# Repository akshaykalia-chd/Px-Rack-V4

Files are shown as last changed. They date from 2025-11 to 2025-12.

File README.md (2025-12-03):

## What is a Px-Rack

Personal Experience Rack, or Px-Rack, is a modular DIY computer rack-style enclosure built for creators who value scalability, customization, and hands-on engineering. Designed to integrate multiple [Mini-ITX](https://en.wikipedia.org/wiki/Mini-ITX) motherboards into a single compact unit, Px-Rack is ideal for homelabs, clustered compute nodes, or multi-OS test environments.

The first use case is [Broadcom VMware Cloud Foundation](https://www.vmware.com/products/cloud-infrastructure/vmware-cloud-foundation). 

### 2-Node Px-Rack Enclosure: ### 
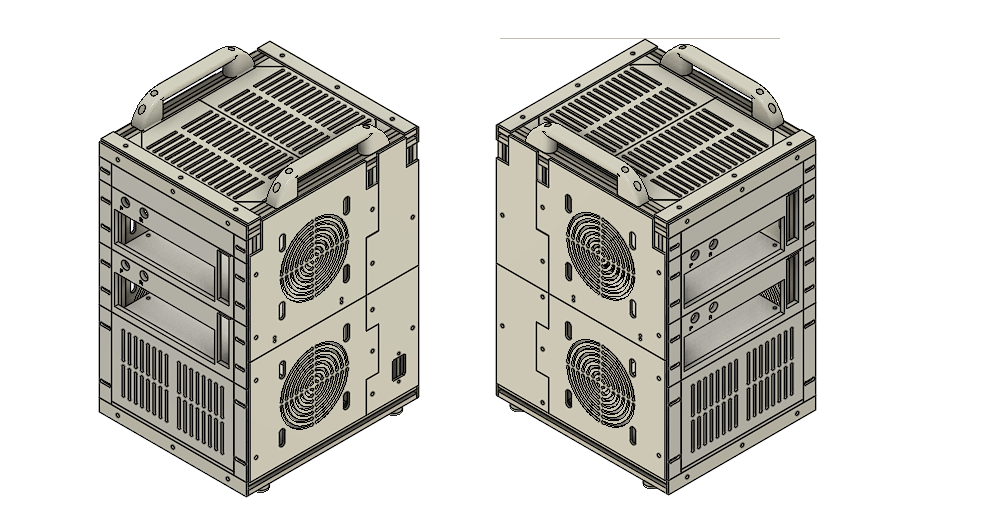
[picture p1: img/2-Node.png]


### 4-Node Px-Rack Enclosure: ### 
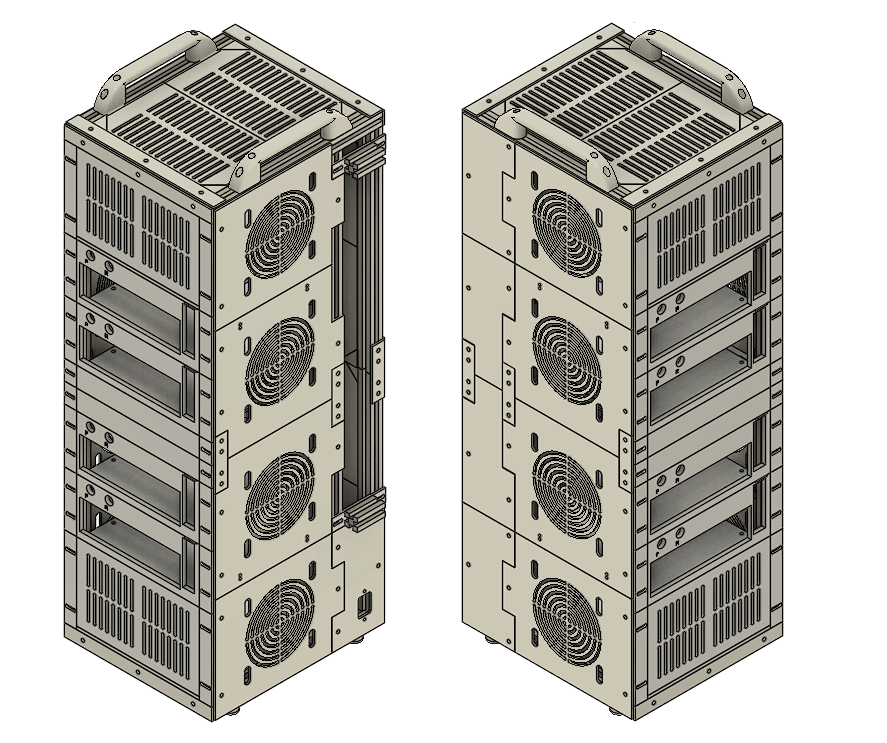
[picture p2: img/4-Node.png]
  

## What sets Px-Rack apart? 

It is Portable, Purpose-Built, and Open-Source

**🔌 Streamlined Power Management**
Unlike traditional racks designed for data centers or server rooms, PX-Rack is purpose-built for commercial hardware. Instead of juggling multiple external power cables, PX-Rack aggregates multiple power supplies into a single external cable using PCT wire connectors.
- No need for extension cords
- No soldering required
- Clean, efficient cable management

**PCT wire connectors:**

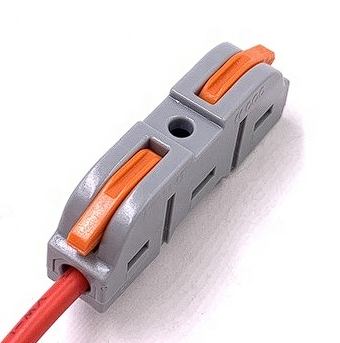
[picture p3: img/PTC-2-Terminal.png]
 
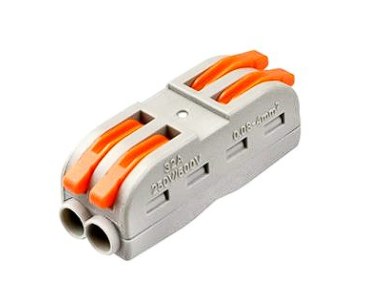
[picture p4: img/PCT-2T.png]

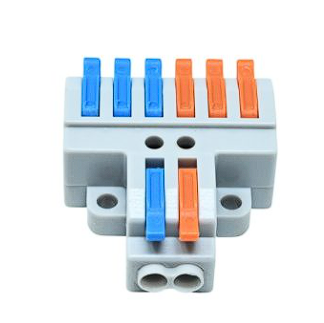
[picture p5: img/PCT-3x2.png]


**📏 Optimized Dimensions**
Width and length — not height — are the critical factors in PX-Rack’s design. This ensures that 10 Gb optical fiber and power cables are neatly tucked inside, reducing clutter and improving accessibility.

**🛠 Maker-Friendly Construction**
Most of PX-Rack’s structural components are 3D-printable, making it accessible and affordable for solo builders and makers.
- STL files available via GitHub
- No proprietary parts
- Community-driven, open-source flexibility

**🌬 Airflow & Multi-Node Freedom**
Whether you’re optimizing airflow, managing cables, or experimenting with multi-node setups, PX-Rack gives you the freedom to build infrastructure your way. It’s a platform designed for experimentation, customization, and scalability.

## Repository stroucture 
```
Px-Rack/
├──2-Node/
│   ├── Data for 2-Node Unit
├──3-Node/   
│   ├── Data for 3-Node Unit
├──4-Node/
│   ├── Data for 4-Node Unit
│
├── STL/
│   ├── ABS/
│   │   ├── PART_001_ABS.stl
│   │   ├── PART_002_ABS.stl
│   │
│   ├── PLA_PETG/
│   │   ├── PART_001_PLA.stl
│   │   ├── PART_002_PLA.stl
└── README.md
    └── Introduction to Px-Rack, build instructions, and licensing.
```
# 📜 Terms and Conditions of Use

By accessing or using the Px-Rack repository, you agree to the following terms:

## 🔧 Personal and Lab Use Only
- This repository is intended solely for **individual, non-commercial use**.
- You may use the provided STL files and documentation to build Px-Rack units for:
  - Personal projects
  - Homelabs
  - Educational setups
  - Non-profit experimentation

## 🚫 Commercial Restrictions
- **Commercial use** of any files, designs, or derivatives is **strictly prohibited** without **explicit written permission** from the repository owner.
- This includes, but is not limited to:
  - Selling printed parts or assembled units
  - Using Px-Rack designs in paid services or commercial installations
  - Distributing modified versions for profit

## 📝 Requesting Permission
- To request commercial usage rights, please contact the repository owner via GitHub or the contact method listed in the main `README.md`.

## 📁 Licensing
- All files are provided "as is" without warranty. Users are responsible for safe printing, assembly, and deployment.
- Redistribution of files must retain original attribution and must not misrepresent the origin or intent of the project.

## 📬 Contact details
- **Name:** Akshay Kalia
- **Email:** akshay@vmzoneblog.com
- **Location:** Bengaluru, Karnataka, India
- **Website:** https://vmzoneblog.com

## FAQs ##

### Why is PDF or STL not loading on Git UI? ###

This behavior is observed when you are connecting to the public GitHub server from a corporate network. Try disabling the VPN and then access the repository.

### What is STL? ###
In 3D printing, STL files are the most common file format used to describe 3D models. STL stands for STereoLithography (or sometimes Standard Triangle Language) and encodes the surface geometry of an object using triangular facets that slicing software can interpret. A slicing software is the tool that converts a 3D model (like an STL file) into layer-by-layer instructions (G-code) that a printer can understand and execute. 

### What is ABS? ###
ABS stands for Acrylonitrile Butadiene Styrene. It is a thermoplastic polymer widely used in 3D printing, especially with FDM (Fused Deposition Modeling) printers. Known for being strong, durable, and impact-resistant, ABS is the same material used in LEGO bricks, car dashboards, and protective housings.

The glass transition temperature of ABS is between 100 and 120 °C. Hence, it is best suited for components operating close to heat-generating parts in the PX-Rack.

### What is PETG? ### 

PETG stands for Polyethylene Terephthalate Glycol-modified. It is a thermoplastic derived from PET (the same plastic used in water bottles), with glycol added to improve durability and reduce brittleness. PETG combines the ease of printing of PLA with the strength and heat resistance of ABS, making it a versatile middle-ground filament.

The glass transition temperature of PETG is between 80 and 100 °C. While it can be used for external parts, it is not suitable for components operating in the vicinity of heat-generating elements in the PX-Rack.

### What is PLA? ###
PLA stands for Polylactic Acid. It is a biodegradable thermoplastic made from renewable resources such as corn starch or sugarcane. PLA is the most widely used filament in desktop 3D printing because it is easy to print, affordable, and environmentally friendly compared to petroleum-based plastics like ABS.

However, the glass transition temperature of PLA lies between 60 and 80 °C. As a result, a large number of PX-Rack components cannot be manufactured using PLA.

PLA should only be used for printing PX-Rack parts as a last resort when printing in PETG is not possible.

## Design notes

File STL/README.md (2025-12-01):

This folder contains all STL files needed to 3D print the various parts of the PX-Rack.

## File Naming Convention

The file names is the folder follow te following pattern 

1. **3d‑YYYY‑MM‑XXX‑XXXXX‑nnnA:** All part numbers with this format must be 3D printed.
   1. *YYYY:* The year in which the part design was last modified. 
   2. *MM:* The month in which the part design was last modified. 
   3. *XXX‑XXXX:* Specifies the material information the part should be printed in. 
   4. *nnnA:* A number followed by a letter. All parts that are joined together to form one unit will share the same numerical portion, followed by an incremental alphabet character.
2. **AAAAAAA‑nnnmm:** All parts with this format must be purchased and cut to length
   1. AAAAAAA: Defines the type of part. 
   2. nnnmm: Length of the part in millimeters. 
3. **AAAAAA‑AAAAA:** All parts with this format must be purchased.

## FAQs ##

### What is STL? ###

In 3D printing, STL files are the most common file format used to describe 3D models. STL stands for STereoLithography (or sometimes Standard Triangle Language) and encodes the surface geometry of an object using triangular facets that slicing software can interpret. A slicing software is the tool that converts a 3D model (like an STL file) into layer-by-layer instructions (G-code) that a printer can understand and execute. 

### What is ABS? ###

ABS stands for Acrylonitrile Butadiene Styrene. It is a thermoplastic polymer widely used in 3D printing, especially with FDM (Fused Deposition Modeling) printers. Known for being strong, durable, and impact-resistant, ABS is the same material used in LEGO bricks, car dashboards, and protective housings.

The glass transition temperature of ABS is between 100 and 120 °C. Hence, it is best suited for components operating close to heat-generating parts in the PX-Rack.

### What is PETG? ### 

PETG stands for Polyethylene Terephthalate Glycol-modified. It is a thermoplastic derived from PET (the same plastic used in water bottles), with glycol added to improve durability and reduce brittleness. PETG combines the ease of printing of PLA with the strength and heat resistance of ABS, making it a versatile middle-ground filament.

The glass transition temperature of PETG is between 80 and 100 °C. While it can be used for external parts, it is not suitable for components operating in the vicinity of heat-generating elements in the PX-Rack.

### What is PLA? ###

PLA stands for Polylactic Acid. It is a biodegradable thermoplastic made from renewable resources such as corn starch or sugarcane. PLA is the most widely used filament in desktop 3D printing because it is easy to print, affordable, and environmentally friendly compared to petroleum-based plastics like ABS.

However, the glass transition temperature of PLA lies between 60 and 80 °C. As a result, a large number of PX-Rack components cannot be manufactured using PLA.

PLA should only be used for printing PX-Rack parts as a last resort when printing in PETG is not possible.

### What quality parameters should be used for 3D prints? ###

You can find these details in the README files located under /STL/ABS and /STL/PLA_PETG.

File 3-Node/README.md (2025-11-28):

## 📑 One Enclosure, Many Paths: The Case Against 3 Node enclosure ##

This section clarifies why PX‑Rack explicitly avoids 3‑Node enclosure configuration, and why the project encourages builders to adopt a 2-Node/4‑Node enclosure as the baseline for scalable, reproducible builds.

**Topology & Symmetry**

1. PX‑Rack emphasizes reproducibility and clarity; a 3‑Node build creates uneven thermal zones and cable routing complexity. 
2. 2-nodes and 4-nodes align with PX‑Rack’s modular philosophy, enabling balanced scaling and straightforward documentation.

**Mechanical & Assembly Considerations**
1. Rack symmetry matters for airflow, load distribution, and cable harnessing. 
2. A 3‑Node setup results in awkward spacing and uneven stress on modular parts. 
3. Documentation clarity suffers because instructions must account for asymmetry, contradicting PX‑Rack’s goal of user‑friendly reproducibility.

**Cost vs. Benefit**
1. The incremental gain from 2 to 3 nodes is marginal compared to the added complexity. 
2. Builders investing in PX‑Rack are better served by scaling directly to 4 nodes, where economies of scale (shared cooling, power distribution, repeatable modules) become meaningful.

**Scalability of the 4‑Node Enclosure**
1. A 4‑Node PX‑Rack enclosure is inherently flexible:
   1. It can host 1 node for entry builds. 
   2. It can expand to 2 nodes. 
   3. It can accommodate 3 nodes if needed, without forcing asymmetry in the enclosure design. 
2. This approach ensures builders are never restricted by their initial enclosure choice. Starting with a 4‑Node frame means growth is always possible without redesign or replacement. 
3. Restricting to a 3-Node enclosure locks builders into a dead‑end path, contradicting PX‑Rack’s philosophy of future‑proof modularity.

## 📌 Conclusion ##

PX‑Rack deliberately avoids 3‑Node configuration because it undermines clarity and reproducibility. Instead, the 2‑Node enclosure is the baseline and 4-Node is the next configuration. 4-Node enclosure supports builds from 1 to 4 nodes, ensuring scalability, symmetry, and future‑proof growth. Builders are encouraged to choose this path to keep every PX‑Rack build accessible, robust, and aligned with the project’s open‑source philosophy.

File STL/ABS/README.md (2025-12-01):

## Folder Contents: ## 

This folder contains 8 STL files as under 

1. 3d-2025-11-ABS-PLUS-001a.stl
2. 3d-2025-11-ABS-PLUS-001b.stl
3. 3d-2025-11-ABS-PLUS-002a.stl
4. 3d-2025-11-ABS-PLUS-002b.stl
5. 3d-2025-11-ABS-PLUS-003a.stl
6. 3d-2025-11-ABS-PLUS-003b.stl
7. 3d-2025-11-ABS-PLUS-004.stl
8. 3d-2025-11-ABS-PLUS-005.stl

The STL must be printed using the following parameters at a minimum. Stronger and higher-quality configurations are acceptable

## 3D Print parameters ##

### Quality ###

1. Material: ABS/ABS+
2. Infill: 50% or above
3. Layer height: 0.28 mm
4. First Layer height: 0.24 mm
5. Precise Wall: True

### Strength ###

1. Top Surface pattern: Rectilinear 
2. Botton Surface pattern:Rectilinear
3. Sparse Infill density: 50% 
4. Sparse Infill pattern: Tri-hexagon
5. Internal solid Infill pattern: Rectilinear

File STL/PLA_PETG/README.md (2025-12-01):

## Folder Contents: ## 

This folder contains 10 STL files as under 

1. 3d-2025-11-PLA-001.stl
2. 3d-2025-11-PLA-002.stl
3. 3d-2025-11-PLA-003.stl
4. 3d-2025-11-PLA-005.stl
5. 3d-2025-11-PLA-006.stl
6. 3d-2025-11-PLA-007.stl
7. 3d-2025-11-PLA-008.stl
8. 3d-2025-11-PLA-009.stl
9. 3d-2025-11-PLA-010.stl
10. 3d-2025-11-PLA-011.stl

The STL must be printed using the following parameters at a minimum. Stronger and higher-quality configurations are acceptable

## 3D Print parameters ##

### Quality ###

1. Material: Ranked recommendation
   1. PETG-Pro
   2. PETG
   3. PLA-Pro
   4. PLA
2. Infill: 50% or above
3. Layer height: 0.28 mm
4. First Layer height: 0.24 mm
5. Precise Wall: True

### Strength ###

1. Top Surface pattern: Rectilinear 
2. Botton Surface pattern:Rectilinear
3. Sparse Infill density: 50% 
4. Sparse Infill pattern: Tri-hexagon
5. Internal solid Infill pattern: Rectilinear

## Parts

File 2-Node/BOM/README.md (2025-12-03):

## Introduction to the 2‑Node PX‑Rack BOM

The file **./BOM/2_NODE_BOM.csv** provides a complete bill of materials required to assemble a 2‑Node PX‑Rack enclosure. This BOM covers all mechanical and structural components necessary for construction.
It is important to note that the listed items do not include any electronic components. The enclosure is designed to give you full flexibility in selecting and integrating your own electronics according to project requirements.
By design, the 2‑Node PX‑Rack supports up to two Mini‑ITX motherboards of your choice. This limitation ensures compactness and structural integrity while still allowing customization of the computing hardware.

The file **./BOM/2_NODE_BOM_electronics.csv** provides a complete bill of materials for the electronic components. Please note that this is a sample list based on the configuration I built. Components that can be customized by the user are marked accordingly.

## Part Naming Convention in the Bill of Materials

The part names is the bill of materials follows the following pattern 
1. **3d‑YYYY‑MM‑XXX‑XXXXX‑nnnA:** All part names with this format must be 3D printed.
   1. *YYYY:* The year in which the part design was last modified. 
   2. *MM:* The month in which the part design was last modified. 
   3. *XXX‑XXXX:* Specifies the material information the part should be printed in. 
   4. *nnnA:* A number followed by a letter. All parts that are joined together to form one unit will share the same numerical portion, followed by an incremental alphabet character.
2. **AAAAAAA‑nnnmm:** All parts names with this format must be purchased and cut to length
   1. AAAAAAA: Defines the type of part. 
   2. nnnmm: Length of the part in millimeters. 
3. **AAAAAA‑AAAAA:** All parts names with this format must be purchased.

### Sample Part Links

**L-Clamp**: https://robu.in/product/easymech-cast-corner-bracket-for-20x20-aluminium-profile-silver-4-pcs/

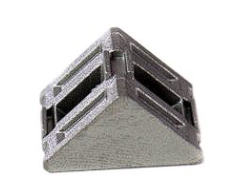
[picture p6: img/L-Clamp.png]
 

**Extrution**:https://robu.in/product/easymech-20x20-t-slot-aluminium-extrusion-profile-1000-mm/

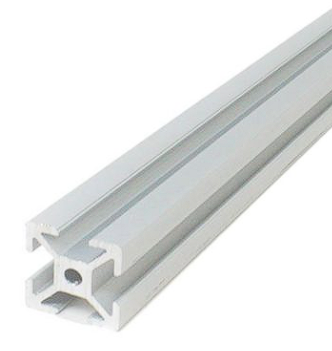
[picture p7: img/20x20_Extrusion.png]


**Mounting T-Nuts**: https://robu.in/product/t-type-m4-nut-for-20x20-aluminium-profile-10-pcs/

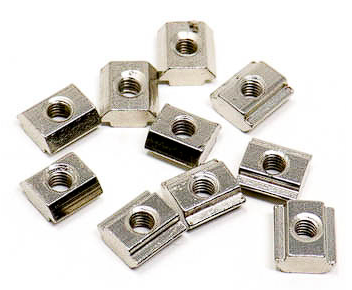
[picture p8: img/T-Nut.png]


**LB12B2-P10F-LANBOO-12mm Economy Push Button Switch**: https://robu.in/product/lb12b2-p10f-lanboo-12mm-economy-push-button-switch-reddc-5-24v1no/ 

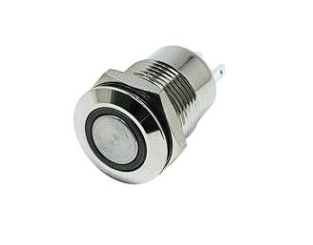
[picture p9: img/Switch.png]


**LB12B2-D1-LANBOO-12mm Economy Push Button Switch Connector**: https://robu.in/product/lb12b2-d1-lanboo-12mm-economy-push-button-switch-connectordc-5-24v/

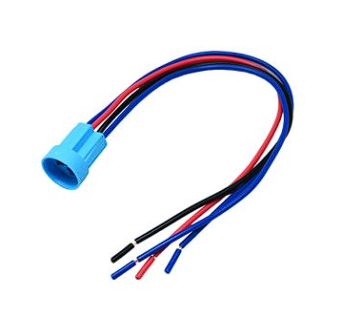
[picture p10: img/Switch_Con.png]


**PCT-223-3 Stationary Type Quick Connection Terminal** : https://robu.in/product/pct-223-3-stationary-type-quick-connection-terminal/

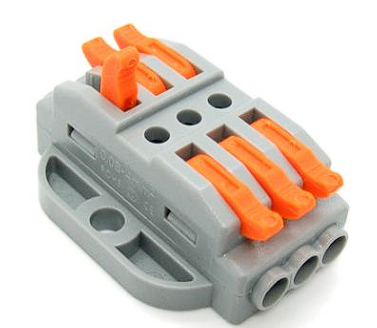
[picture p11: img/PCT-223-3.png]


**LT-633(SPL-63) Stationary, Type Quick Connection, Terminal** : https://robu.in/product/lt-633spl-63-stationary-type-quick-connection-terminal/ 

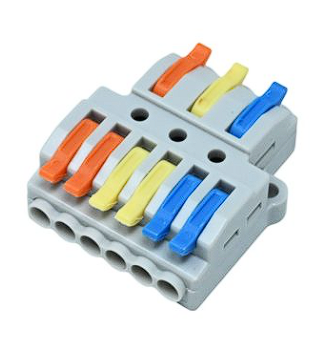
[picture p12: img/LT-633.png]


**LT-933(SPL-93) Stationary Type Quick Connection Terminal**: https://robu.in/product/lt-933spl-93-stationary-type-quick-connection-terminal/ 

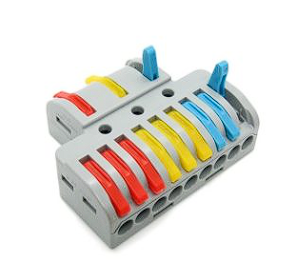
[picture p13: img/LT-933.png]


**IEC C14 Power Inlet Socket with Wires Pre Soldred (Without Fuse)** : https://u1104017.en.made-in-china.com/product/rZBGPcjKlWkD/China-IEC-320-C14-Male-3-Pins-Screw-Mount-Inlet-AC-Power-Plug-Adapter-Connector-Socket-AC-250V-10A-Black-w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



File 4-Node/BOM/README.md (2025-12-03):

## Introduction to the 4‑Node PX‑Rack BOM

The file **./BOM/4_NODE_BOM.csv** provides a complete bill of materials required to assemble a 4‑Node PX‑Rack enclosure. This BOM covers all mechanical and structural components necessary for construction.
It is important to note that the listed items do not include any electronic components. The enclosure is designed to give you full flexibility in selecting and integrating your own electronics according to project requirements.
By design, the 4‑Node PX‑Rack supports up to four Mini‑ITX motherboards of your choice. This limitation ensures compactness and structural integrity while still allowing customization of the computing hardware.

The file **./BOM/4_NODE_BOM_electronics.csv** provides a complete bill of materials for the electronic components. Please note that this is a sample list based on the configuration I built. Components that can be customized by the user are marked accordingly.

## Part Naming Convention in the Bill of Materials

The part names is the bill of materials follows the following pattern 
1. **3d‑YYYY‑MM‑XXX‑XXXXX‑nnnA:** All part names with this format must be 3D printed.
   1. *YYYY:* The year in which the part design was last modified. 
   2. *MM:* The month in which the part design was last modified. 
   3. *XXX‑XXXX:* Specifies the material information the part should be printed in. 
   4. *nnnA:* A number followed by a letter. All parts that are joined together to form one unit will share the same numerical portion, followed by an incremental alphabet character.
2. **AAAAAAA‑nnnmm:** All parts names with this format must be purchased and cut to length
   1. AAAAAAA: Defines the type of part. 
   2. nnnmm: Length of the part in millimeters. 
3. **AAAAAA‑AAAAA:** All parts names with this format must be purchased.

### Sample Part Links

**L-Clamp**: https://robu.in/product/easymech-cast-corner-bracket-for-20x20-aluminium-profile-silver-4-pcs/

 

**Extrution**:https://robu.in/product/easymech-20x20-t-slot-aluminium-extrusion-profile-1000-mm/



**Mounting T-Nuts**: https://robu.in/product/t-type-m4-nut-for-20x20-aluminium-profile-10-pcs/



**LB12B2-P10F-LANBOO-12mm Economy Push Button Switch**: https://robu.in/product/lb12b2-p10f-lanboo-12mm-economy-push-button-switch-reddc-5-24v1no/ 



**LB12B2-D1-LANBOO-12mm Economy Push Button Switch Connector**: https://robu.in/product/lb12b2-d1-lanboo-12mm-economy-push-button-switch-connectordc-5-24v/



**PCT-223-3 Stationary Type Quick Connection Terminal** : https://robu.in/product/pct-223-3-stationary-type-quick-connection-terminal/



**LT-633(SPL-63) Stationary, Type Quick Connection, Terminal** : https://robu.in/product/lt-633spl-63-stationary-type-quick-connection-terminal/ 



**LT-933(SPL-93) Stationary Type Quick Connection Terminal**: https://robu.in/product/lt-933spl-93-stationary-type-quick-connection-terminal/ 



**IEC C14 Power Inlet Socket with Wires Pre Soldred (Without Fuse)** : https://u1104017.en.made-in-china.com/product/rZBGPcjKlWkD/China-IEC-320-C14-Male-3-Pins-Screw-Mount-Inlet-AC-Power-Plug-Adapter-Connector-Socket-AC-250V-10A-Black-w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



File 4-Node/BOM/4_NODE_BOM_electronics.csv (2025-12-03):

Product | Description | Quantity | Customizable
MSI MPG B850I Edge Ti WiFi AM5 Mini-ITX | Mother Board | 4 | Yes, you can use other AM5 MotherBoards as well
AMD RYZEN 9 9950X AM5 DESKTOP PROCESSOR (100-100001277WOF) | CPU | 4 | Yes, Any AM5 CPU should do
128GB (64GBX2) DDR5 6400MHZ UDIMM DESKTOP RAM | RAM | 4 | Yes
512GB SATA III INTERNAL SSD | Boot Disk | 4 | Yes
500GB M.2 NVME INTERNAL SSD | Memory Tier | 4 | Yes
2TB M.2 NVME INTERNAL SSD | vSAN | 4 | Yes
400 Watt ATX Power | Power | 4 | Yes
Noctua NH-L9a-AM5 92mm | CPU Cooler | 4 | Yes
Intel 10G Nic x710-DA2 SFP+ | 10g Nic SPF+ | 4 | Yes, any Supprted 10G 10g Nic with SPF+ or RJ45 Should do
TP-Link TL-SM5310-T | 10GBase-T RJ45 SFP+ Module | SPF+ to RJ 45 | 2 | Yes, Buy based on Switch selection
TP-Link TL-SX3016F | 16 Port 10G SFP+ | 10G Switch | 1 | Yes, any 10G swith with VLAN Support should do
SPF+ cable | SPF+ cable | 8 | Yes, Buy based on Switch selection
LB12B2-P10F-LANBOO-12mm Economy Push Button Switch | Power & Reset switch | 8 | No
LB12B2-D1-LANBOO-12mm Economy Push Button Switch Connector | Power & Reset switch Wires | 8 | No
PCT-223-3 Stationary Type Quick Connection Terminal | PCT wire connectors | 4 | No
LT-633(SPL-63) Stationary, Type Quick Connection, Terminal | PCT wire connectors | 2 | No
LT-933(SPL-93) Stationary Type Quick Connection Terminal | PCT wire connectors | 1 | No
IEC C14 Power Inlet Socket with Wires Pre Soldered (Without Fuse) | AC Power Inlet | 1 | No

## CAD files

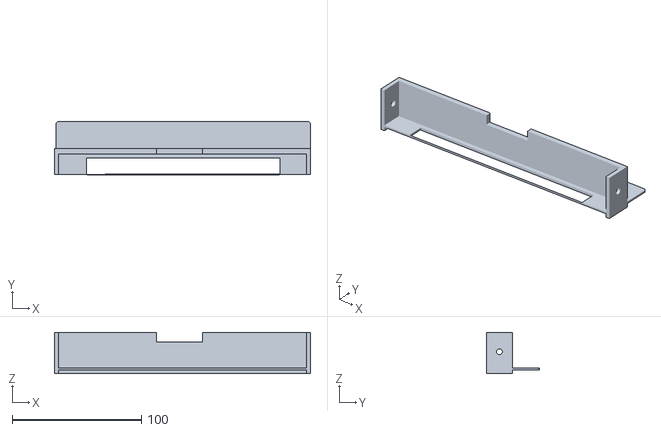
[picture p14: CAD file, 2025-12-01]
STL/ABS/3d-2025-11-ABS-PLUS-001b.stl
198.0 x 41.0 x 32.0

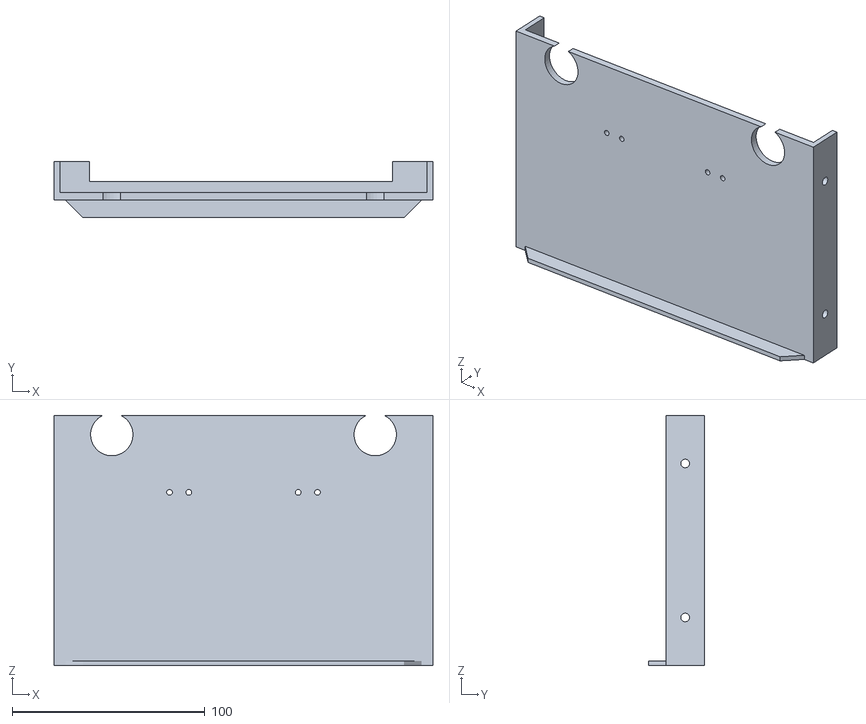
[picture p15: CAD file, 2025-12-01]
STL/ABS/3d-2025-11-ABS-PLUS-003b.stl
196.8 x 29.0 x 130.0

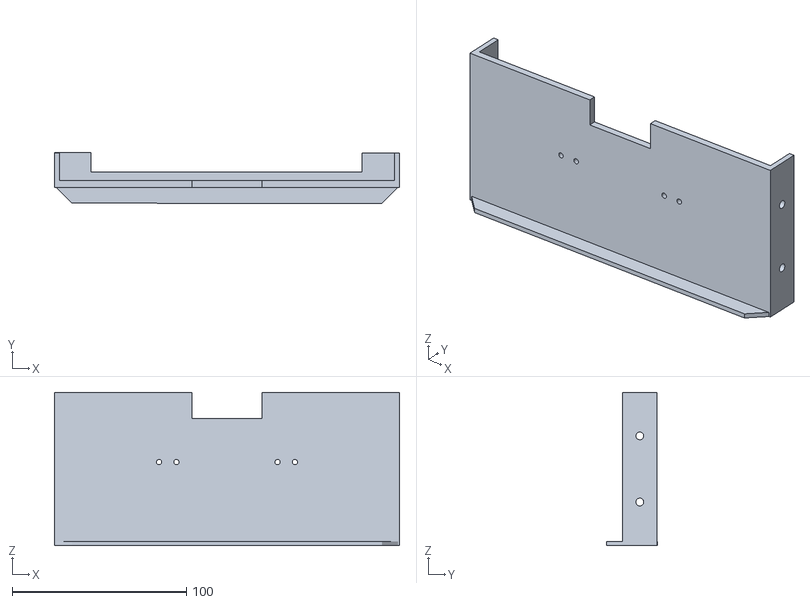
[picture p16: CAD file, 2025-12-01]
STL/ABS/3d-2025-11-ABS-PLUS-002b.stl
198.0 x 29.0 x 88.0

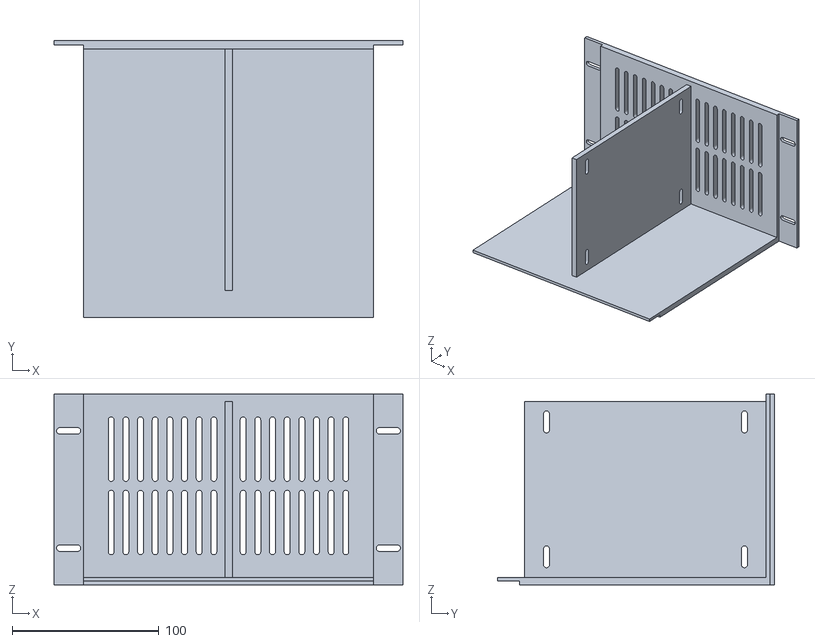
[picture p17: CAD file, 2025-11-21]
STL/ABS/3d-2025-11-ABS-PLUS-003a.stl
238.0 x 189.0 x 130.0

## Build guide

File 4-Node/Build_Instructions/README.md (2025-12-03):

## PX-Rack 4-Node Enclosure Assembly Overview
The directory contains PDF files showing the various steps involved in assembling the PX-Rack 4-node enclosure.

Each step includes a parts list along with the required mounting screws and nuts. Before starting to follow the drawings in this section, make sure you have purchased all the required components and 3D-printed all the necessary parts.

**The build steps do not cover electronics integration.** This is intentional. Before ordering the electronics and attempting integration, I recommend that you fully assemble the PX-Rack enclosure.

However, Electronics integration will take place after **Step-3**, and by the end of **Step-5** all electronics should be in place, except for the ventilation fans. The fans will be installed after **Step-5** and before **Step-7**.

*Electronics integration is slightly nuanced and cannot be explained adequately using drawings. I will include videos for this process in the near future.*



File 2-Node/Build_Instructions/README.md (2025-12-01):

## PX-Rack 2-Node Enclosure Assembly Overview
The directory contains PDF files showing the various steps involved in assembling the PX-Rack 2-node enclosure.

Each step includes a parts list along with the required mounting screws and nuts. Before starting to follow the drawings in this section, make sure you have purchased all the required components and 3D-printed all the necessary parts.

**The build steps do not cover electronics integration.** This is intentional. Before ordering the electronics and attempting integration, I recommend that you fully assemble the PX-Rack enclosure.

However, Electronics integration will take place after **Step-2**, and by the end of **Step-3** all electronics should be in place, except for the ventilation fans. The fans will be installed after **Step-4** and before **Step-5**.

*Electronics integration is slightly nuanced and cannot be explained adequately using drawings. I will include videos for this process in the near future.*



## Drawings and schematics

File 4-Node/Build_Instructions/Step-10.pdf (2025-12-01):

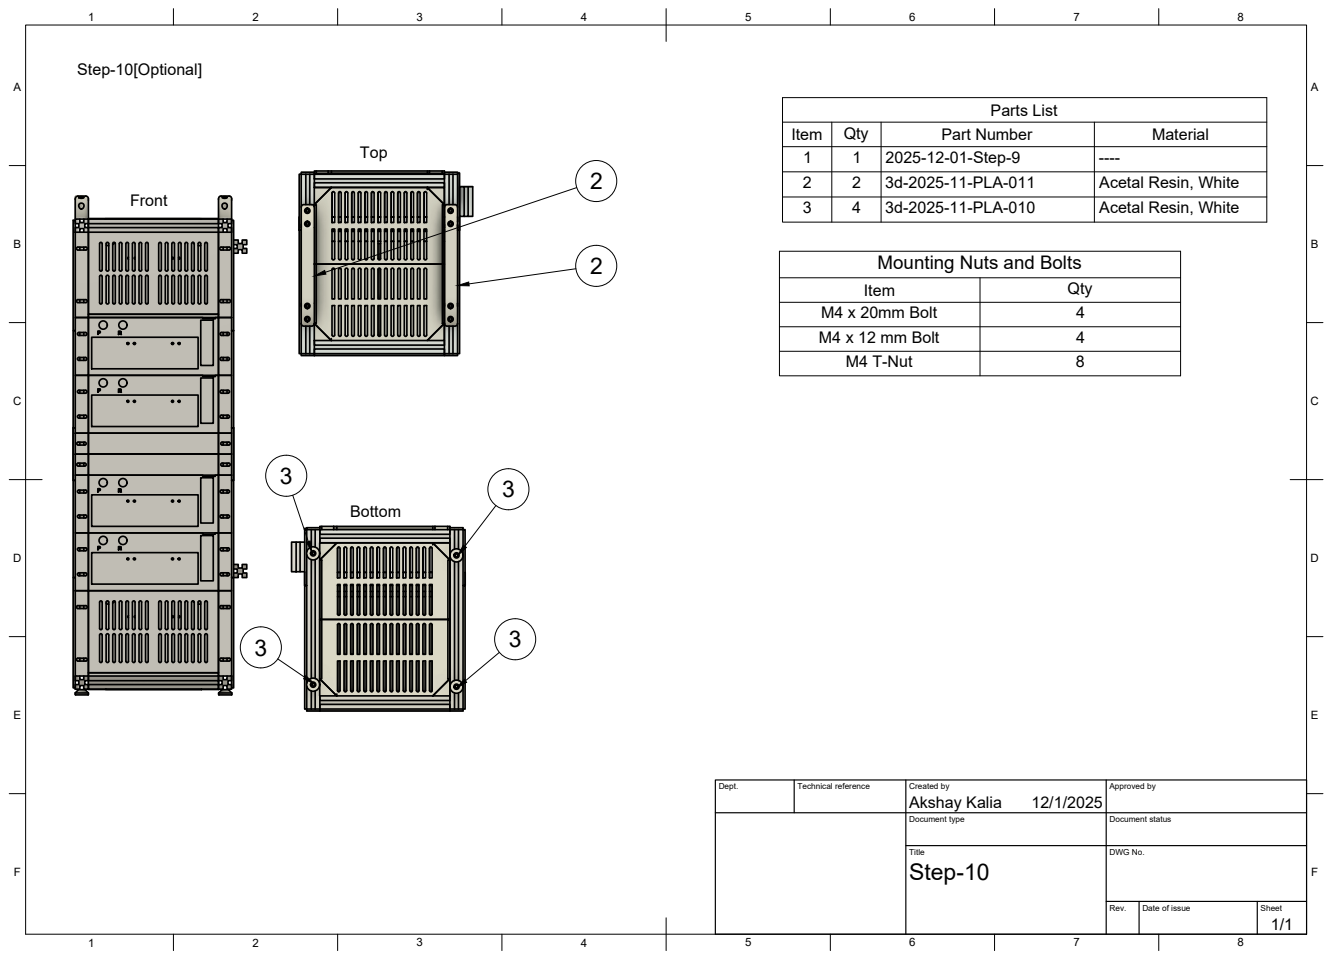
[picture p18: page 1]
Title; DWG No.; Rev.; Date of issue; Sheet; Parts List

Item | Qty | Part Number | Material
1 | 2 1 | 3d-2025-11-PLA-011 2025-12-01-Step-9 | ---- 2 Acetal Resin, White

3 | 4 | 3d-2025-11-PLA-010 | Acetal Resin, White

Mounting Nuts and Bolts

Item | Qty
M4 x 20mm Bolt | 4
M4 x 12 mm Bolt | 4
M4 T-Nut | 8

Dept. | Technical reference | Created by Akshay Kalia 12/1/2025 | Approved by

Document type | Document status

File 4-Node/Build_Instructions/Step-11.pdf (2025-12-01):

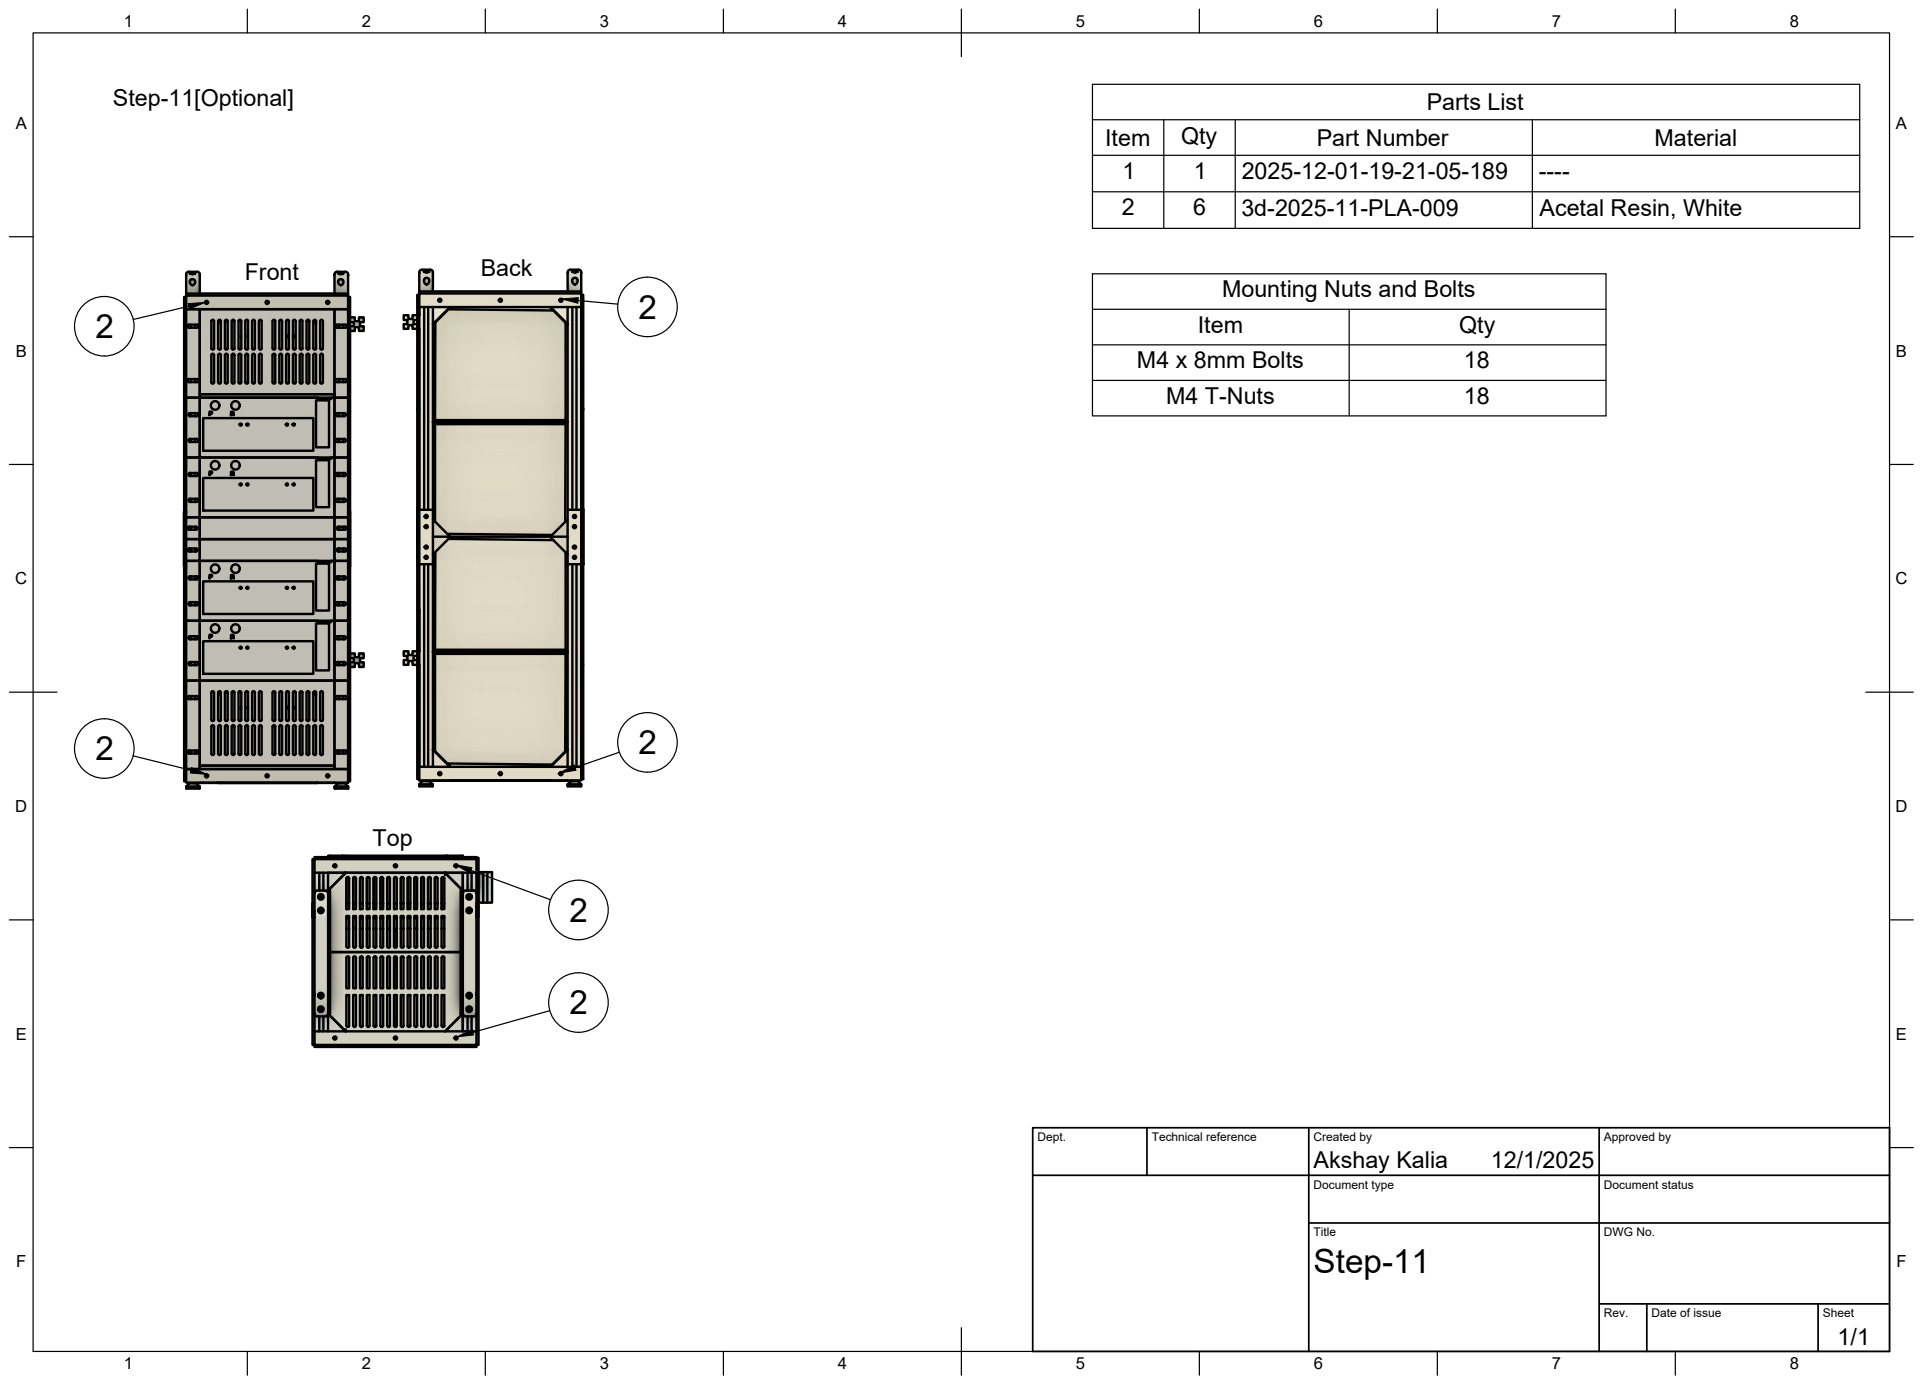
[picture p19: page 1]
Title; DWG No.; Rev.; Date of issue; Sheet; Parts List

Item | Qty | Part Number | Material
1 | 6 1 | 3d-2025-11-PLA-009 2025-12-01-19-21-05-189 | ---- 2 Acetal Resin, White

Mounting Nuts and Bolts

Item | Qty
M4 x 8mm Bolts | 18
M4 T-Nuts | 18

Dept. | Technical reference | Created by Akshay Kalia 12/1/2025 | Approved by

Document type | Document status

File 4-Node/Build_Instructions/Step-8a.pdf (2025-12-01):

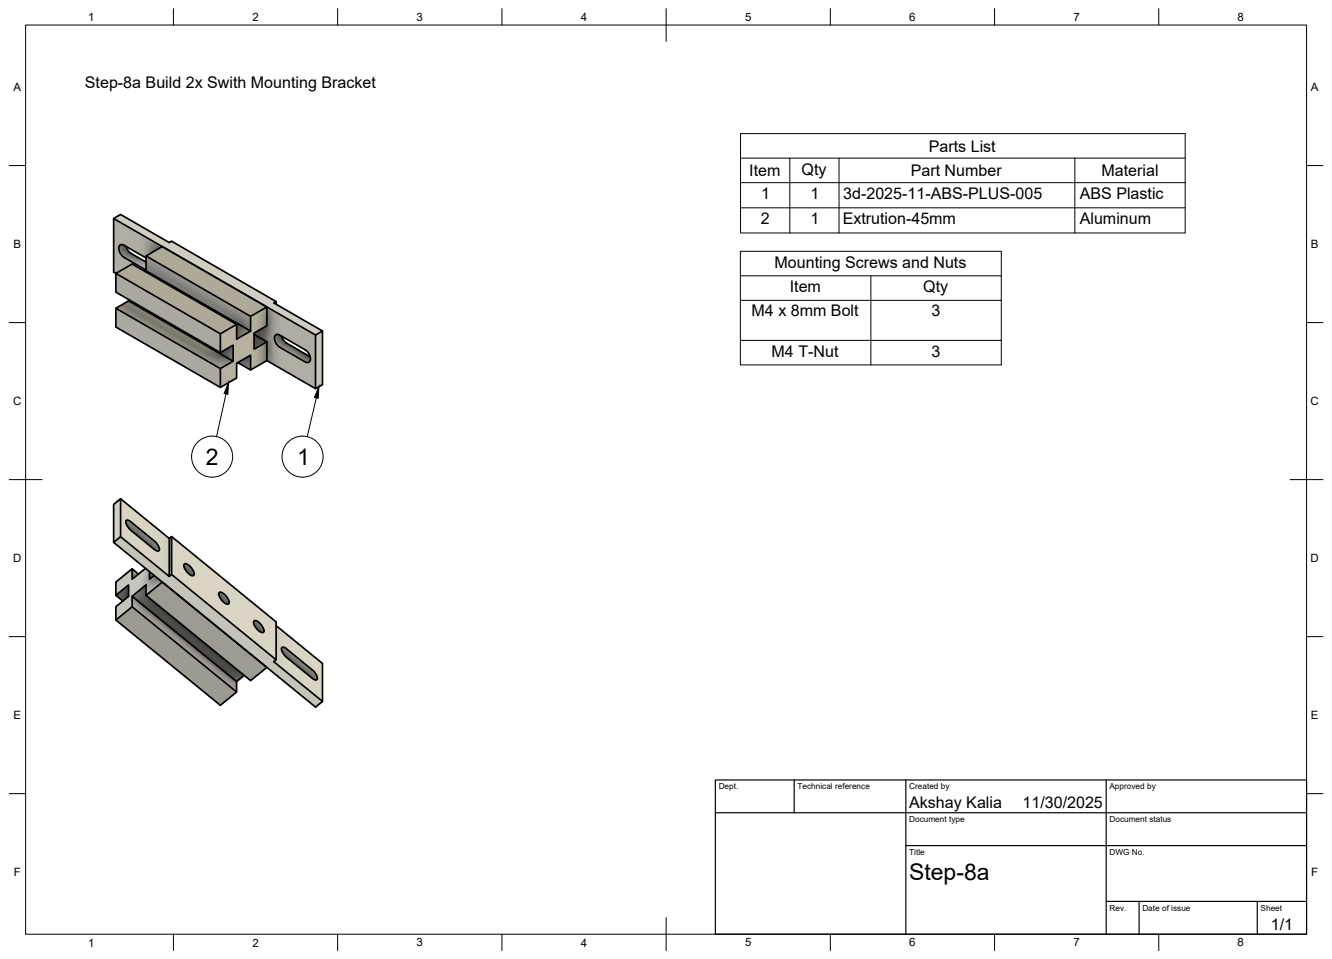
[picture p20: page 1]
Title; DWG No.; Rev.; Date of issue; Sheet; Parts List

Step-8a Build 2x Swith Mounting Bracket

Item | Qty | Part Number | Material
1 | 1 | 3d-2025-11-ABS-PLUS-005 | ABS Plastic
2 | 1 | Extrution-45mm | Aluminum

Mounting Screws and Nuts

Item | Qty
M4 x 8mm Bolt | 3

M4 T-Nut | 3

Dept. | Technical reference | Created by Akshay Kalia 11/30/2025 | Approved by

Document type | Document status

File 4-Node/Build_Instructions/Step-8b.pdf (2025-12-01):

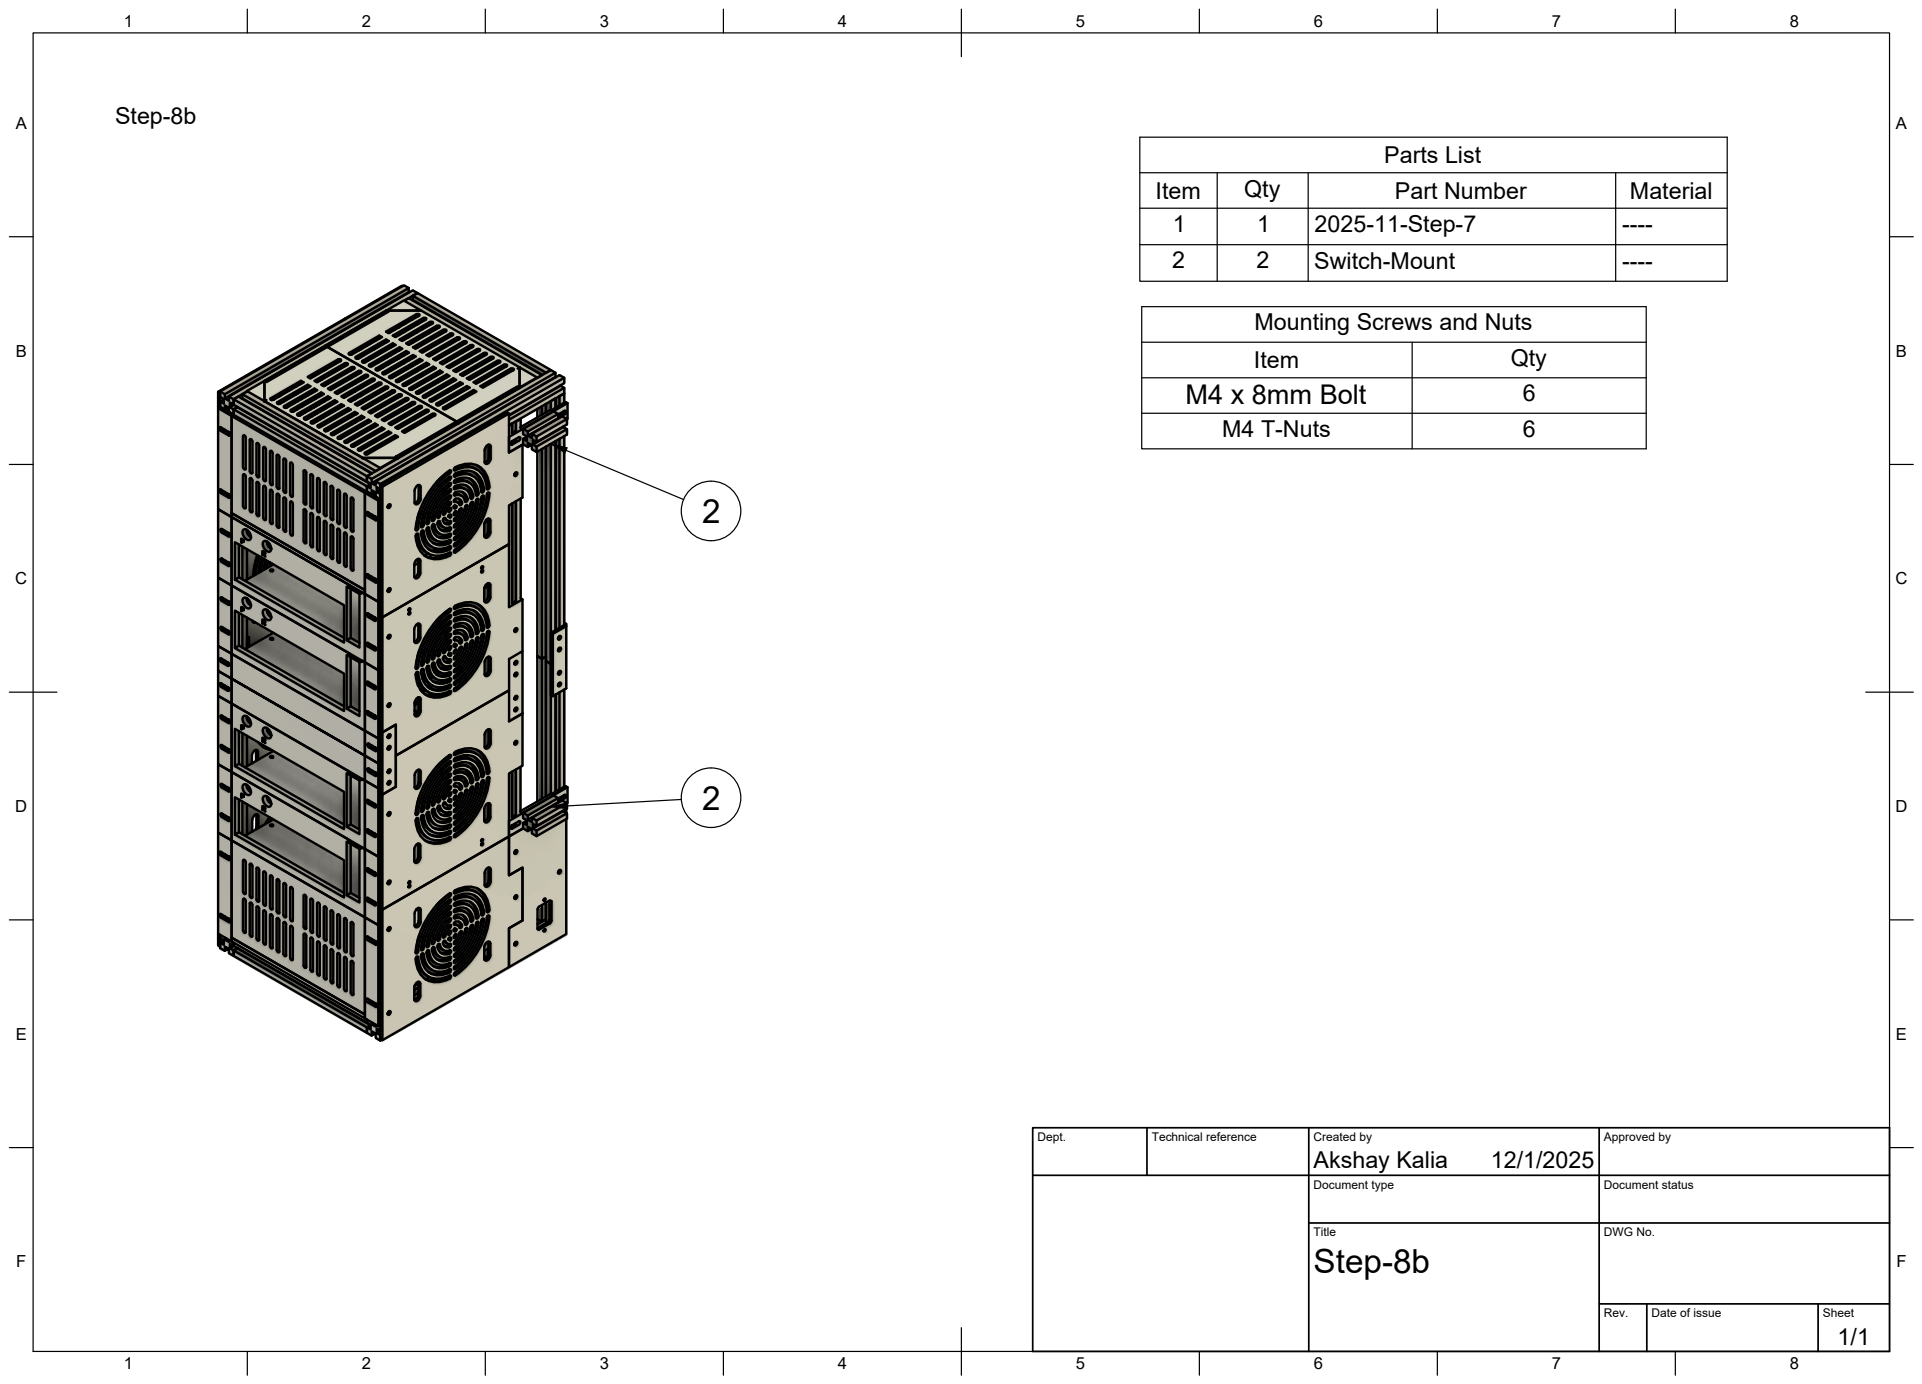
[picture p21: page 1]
Title; DWG No.; Rev.; Date of issue; Sheet; Parts List

Item | Qty | Part Number | Material
1 | 2 1 | Switch-Mount 2025-11-Step-7 | ---- 2 ----

Mounting Screws and Nuts

Item | Qty
M4 x 8mm Bolt | 6
M4 T-Nuts | 6

Dept. | Technical reference | Created by Akshay Kalia 12/1/2025 | Approved by

Document type | Document status

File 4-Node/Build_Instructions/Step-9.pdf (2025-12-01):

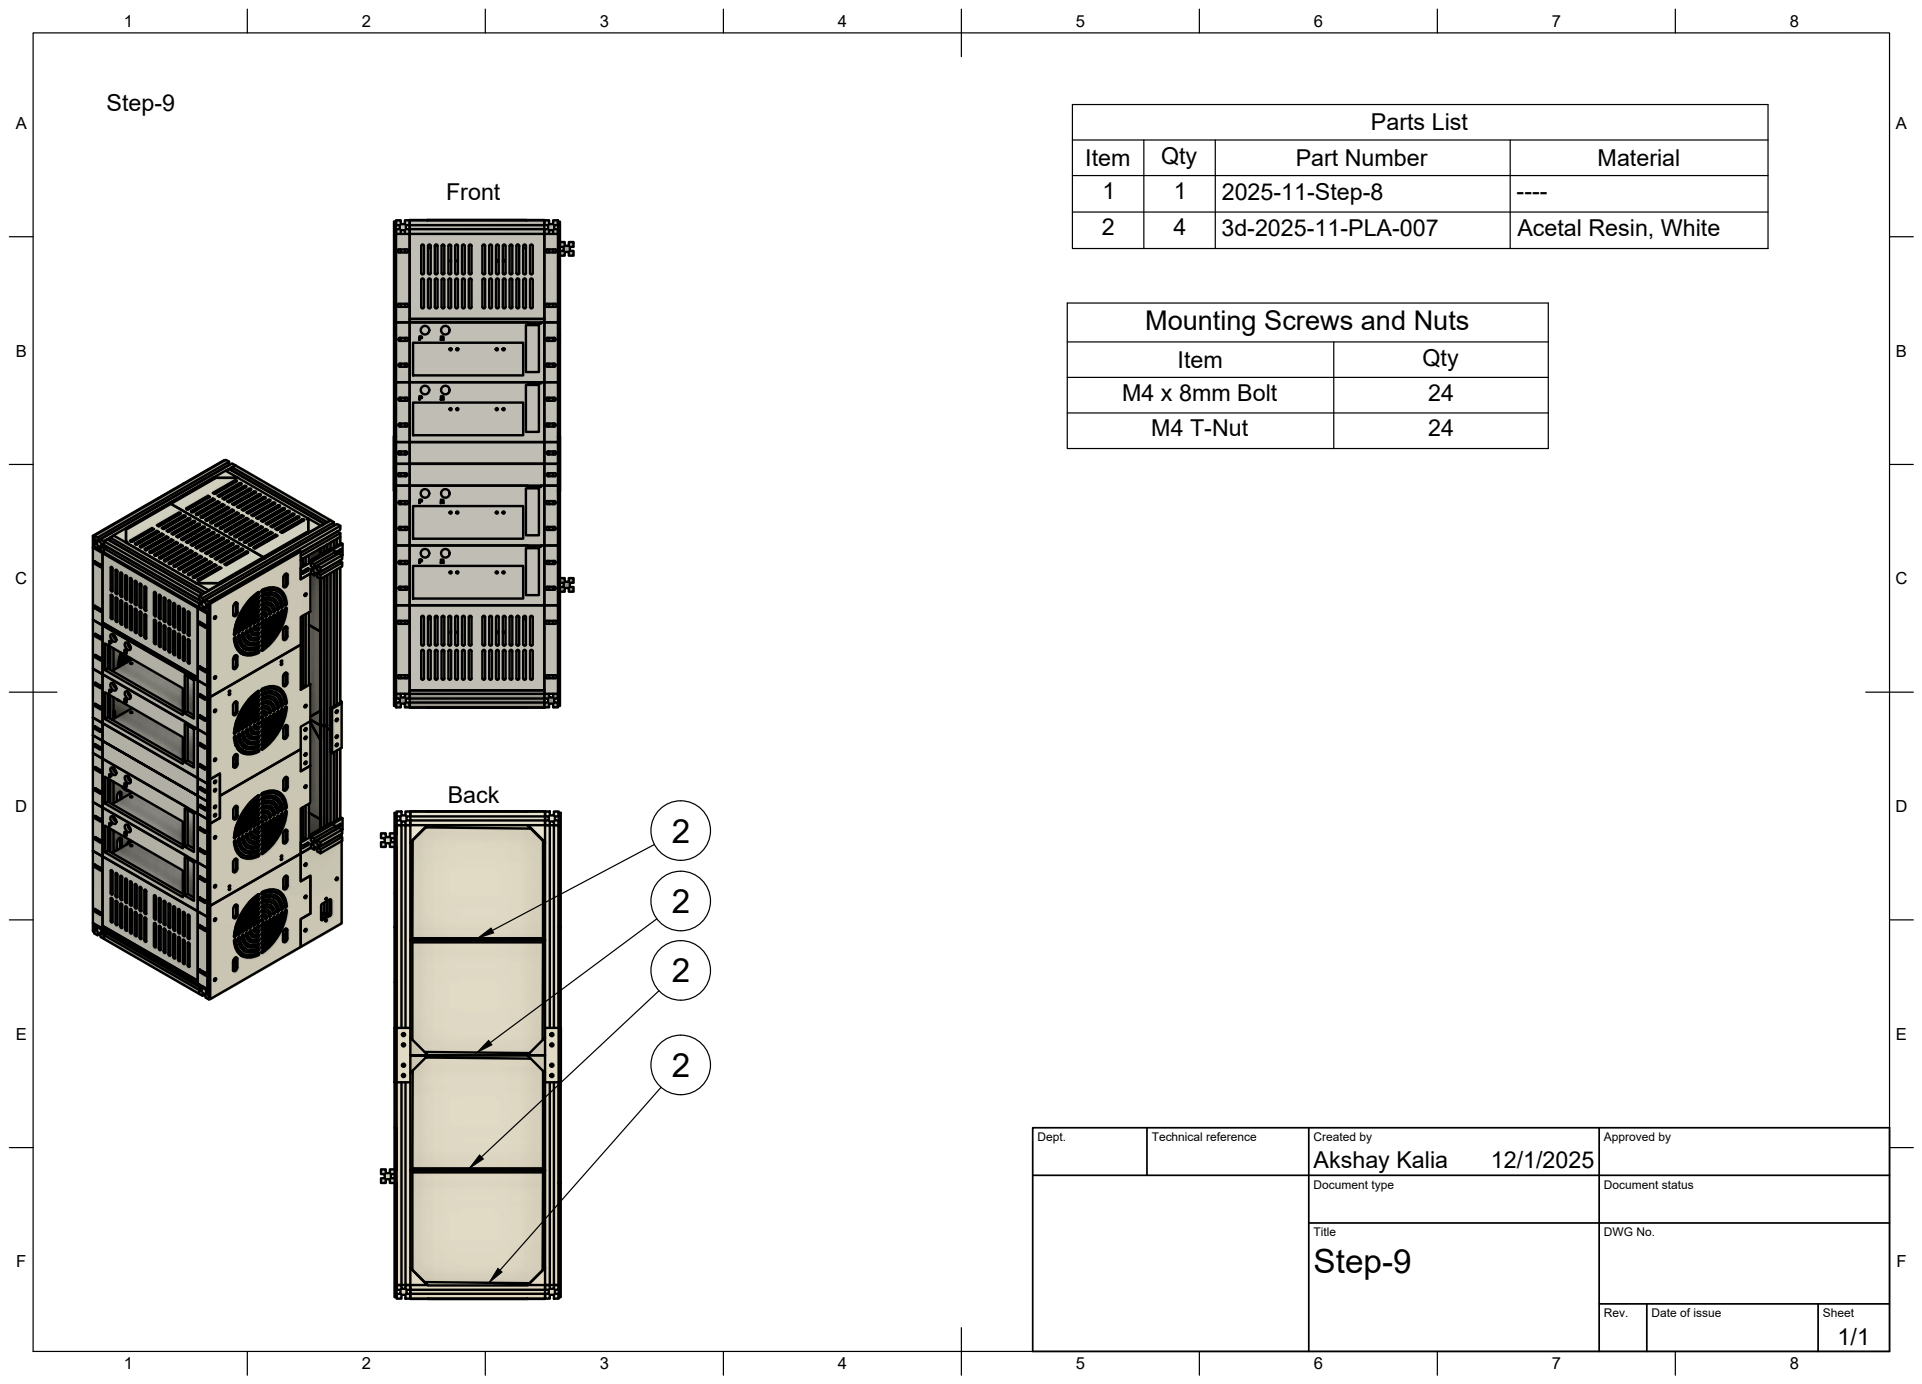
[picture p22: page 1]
Title; DWG No.; Rev.; Date of issue; Sheet; Parts List

Item | Qty | Part Number | Material
1 | 4 1 | 3d-2025-11-PLA-007 2025-11-Step-8 | ---- 2 Acetal Resin, White

Mounting Screws and Nuts

Item | Qty
M4 x 8mm Bolt | 24
M4 T-Nut | 24

Dept. | Technical reference | Created by Akshay Kalia 12/1/2025 | Approved by

Document type | Document status

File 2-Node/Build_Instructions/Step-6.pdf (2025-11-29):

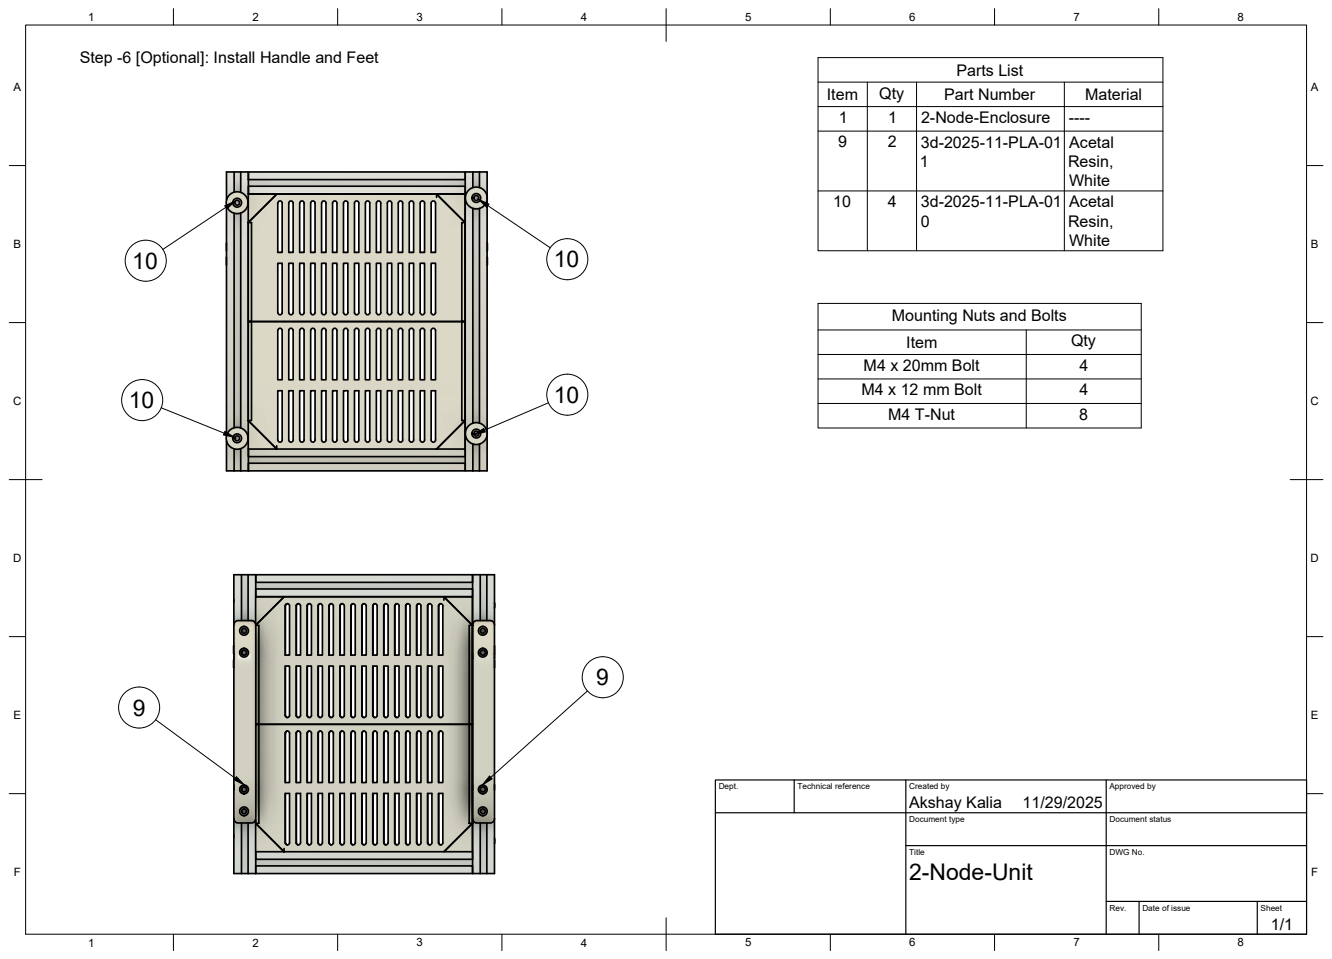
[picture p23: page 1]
Title; DWG No.; Rev.; Date of issue; Sheet; Parts List

Step -6 [Optional]: Install Handle and Feet

Item | Qty | Part Number | Material
1 | 2 1 | 3d-2025-11-PLA-01 2-Node-Enclosure | ---- 9

1 | Acetal Resin, White

10 | 4 | 3d-2025-11-PLA-01 0 | Acetal Resin, White

Mounting Nuts and Bolts

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

Dept. | Technical reference | Created by Akshay Kalia 11/29/2025 | Approved by

Document type | Document status

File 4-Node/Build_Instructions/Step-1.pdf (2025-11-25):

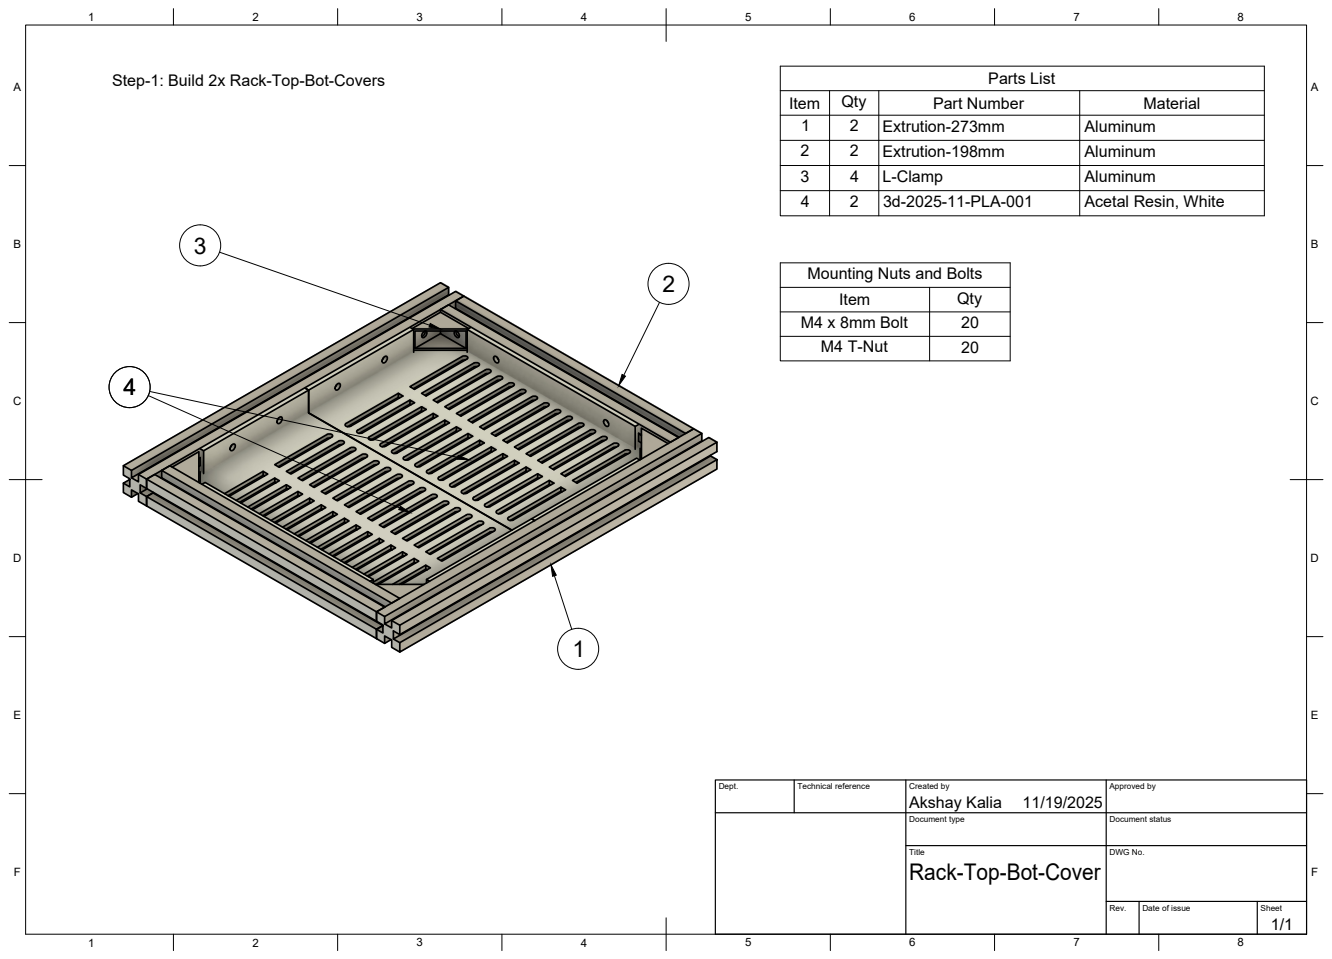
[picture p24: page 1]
Title; DWG No.; Rev.; Date of issue; Sheet; Parts List

Step-1: Build 2x Rack-Top-Bot-Covers

Item | Qty | Part Number | Material
1 | 2 | Extrution-273mm | Aluminum
2 | 2 | Extrution-198mm | Aluminum
3 | 4 | L-Clamp | Aluminum
4 | 2 | 3d-2025-11-PLA-001 | Acetal Resin, White

Mounting Nuts and Bolts

Item | Qty
M4 x 8mm Bolt | 20
M4 T-Nut | 20

Dept. | Technical reference | Created by Akshay Kalia 11/19/2025 | Approved by

Document type | Document status

Rack-Top-Bot-Cover

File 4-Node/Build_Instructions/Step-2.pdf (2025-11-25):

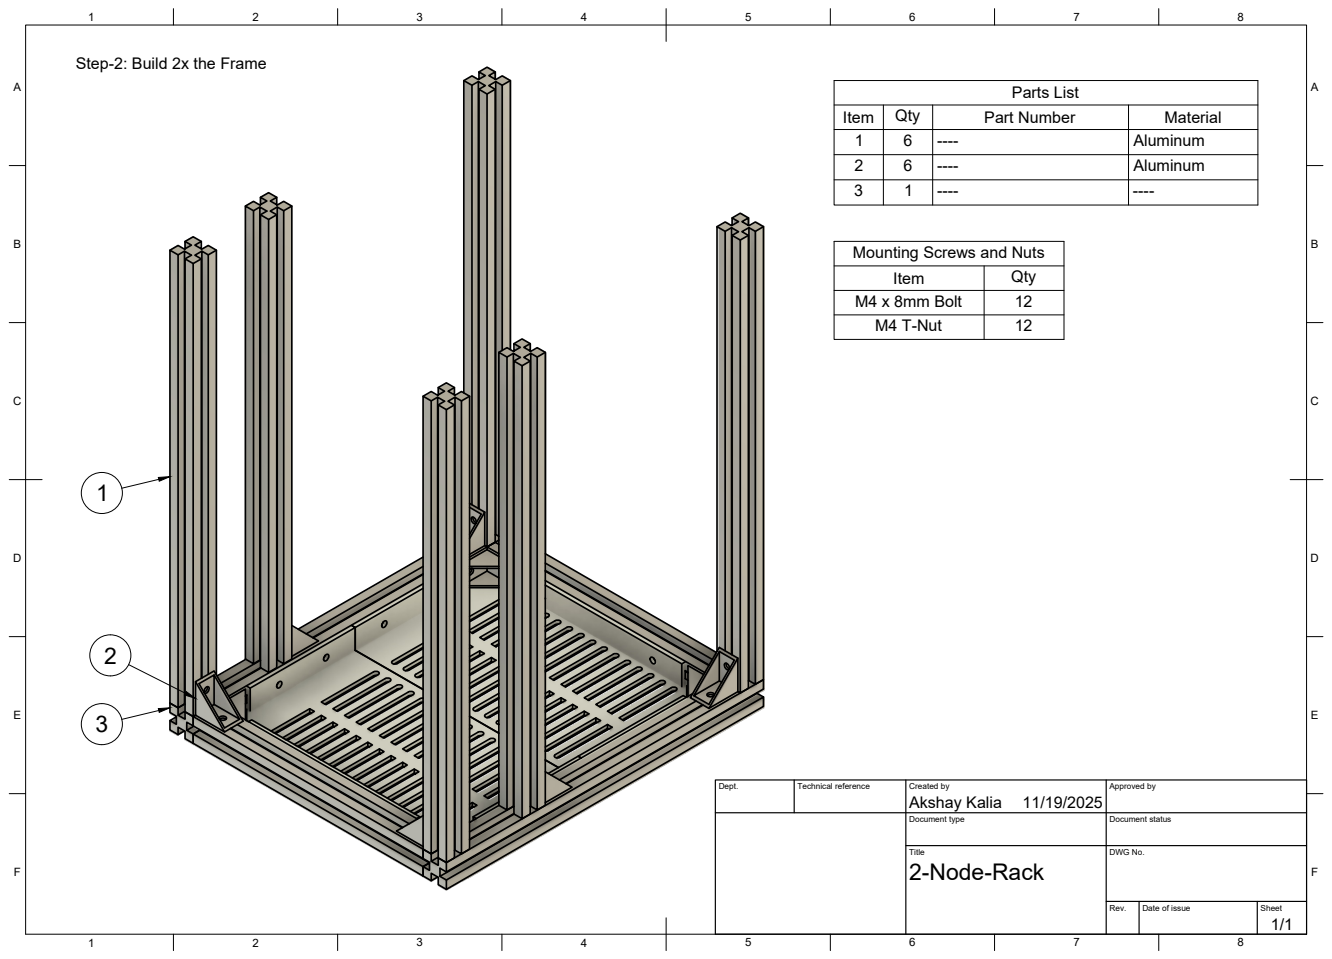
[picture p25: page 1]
Title; DWG No.; Rev.; Date of issue; Sheet; Parts List

Step-2: Build 2x the Frame

Item | Qty | Part Number | Material
1 | 6 | ---- | Aluminum
2 | 6 | ---- | Aluminum
3 | 1 | ---- | ----

Mounting Screws and Nuts

Item | Qty
M4 x 8mm Bolt | 12
M4 T-Nut | 12

Dept. | Technical reference | Created by Akshay Kalia 11/19/2025 | Approved by

Document type | Document status

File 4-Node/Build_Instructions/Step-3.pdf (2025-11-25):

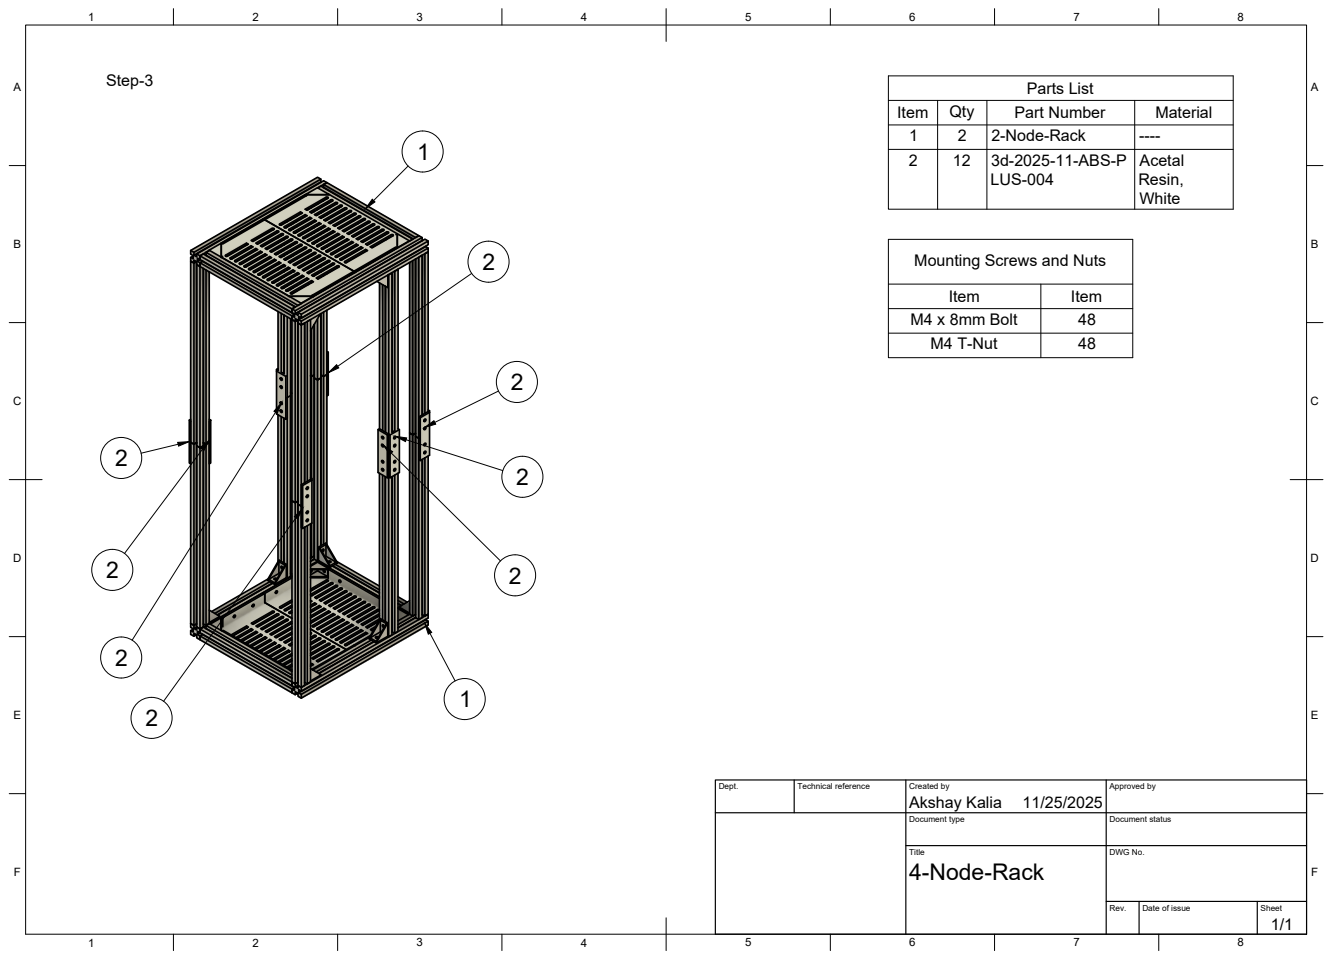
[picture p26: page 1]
Title; DWG No.; Rev.; Date of issue; Sheet; Parts List

Item | Qty | Part Number | Material
1 | 12 2 | 3d-2025-11-ABS-P 2-Node-Rack | ---- 2

LUS-004 | Acetal Resin, White

Mounting Screws and Nuts

Item | Item
M4 x 8mm Bolt | 48
M4 T-Nut | 48

Dept. | Technical reference | Created by Akshay Kalia 11/25/2025 | Approved by

Document type | Document status

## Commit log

2025-11-21 Validation Print failed assembly due to a few mm clearance issue
    [3d-2025-11-ABS-PLUS-003a.stl]
2025-12-01 Updates ReadMe and Build Steps
    [3d-2025-11-ABS-PLUS-001b.stl, 3d-2025-11-ABS-PLUS-002b.stl, 3d-2025-11-ABS-PLUS-003b.stl]
2025-12-03 Updates Img names and readme
    [2_NODE_BOM_electronics.csv, 4_NODE_BOM_electronics.csv]
